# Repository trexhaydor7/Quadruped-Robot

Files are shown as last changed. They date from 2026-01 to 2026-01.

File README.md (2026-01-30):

# Quadruped-Robot
A servo-driven robotic dog controlled by a Raspberry Pi for smooth movement and intelligent autonomous behavior. Along with an intent to implement robust algorithims and mechnanical design, this project is aimed to be open-sourced, well-documented, and meant to spark new ideas in others.

<div align="center">
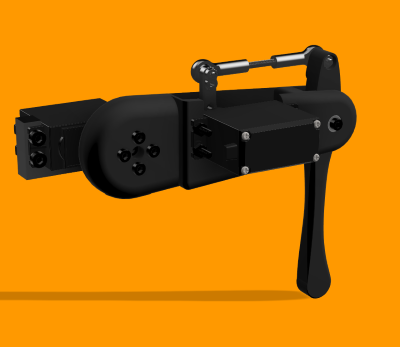
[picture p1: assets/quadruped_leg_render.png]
Quadruped leg design
  
</div>

# Technical Details

This project includes two major software components, a custom CLI interface, named QGC (Quadruped Guidance Computer), and a trained AI model using the Jetson Nano Orion. At the time of writing, neither of these are fully implemented, but I have plans to implement them in the future due to my interest in low-level programming, AI models, and embedded systems engineering. Furthermore, all CAD for the robot was designed by me in Fusion 360 and was printed using on the Bambu Lab H2S using either generic PLA or PETG HF (for particularly critical parts where strength is needed). Other than 3D-printed parts, all parts were ordered from a varity of suppliers, however many Amazon. The electronics of the quadruped robot are composed of the Jetson Orion Nano for high-speed computation and high-level instructions, and the low-level custom PCB that serves as a PWM-driver for all 12 Hi-Torque MG996R servo motors.

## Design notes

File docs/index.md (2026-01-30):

<!--
  ===================    !!READ THIS NOTICE!!   ====================
  DO NOT edit this file manually. Your changes WILL BE OVERWRITTEN!
  This journal is auto generated and updated by Hack Club Blueprint.
  To edit this file, please edit your journal entries on Blueprint.
  ==================================================================
-->

## 10/26/2025 - Prototyped Parts  

I prototyped the servo mount and upper linkage (_femur_) for the **MG996R Hi Torque Servo Motors** that I will be using, utilizing **M3 screws and bolts** to make a more robust build. It took a while to design the servo mount because I spent a lot of time reiterating on the mounting choice (initially I was going to use heated inserts), but bolts will be the most reliable for now. After this I hope to design the lower linkage (_tibia_) of the robot and also the hip mechanism, which could use a differential or some variation.

**Servo Mount for MG996R** 


**Upper Linkage (_Femur_)** 


## 10/31/2025 - Improved Femur Part  

Today, I reiterated on the femur design, **majorly** improving both the **structural aspects**, **functionality** (added room for the second room for controlling the tibia), and the technical side of my **CAD software**, Fusion 360, by assigning more variables for redundant values, using appropriate joints, etc. I think I did a good job of working out the screw tolerances to mount the servo motor to the femur shell. However I think I can work on the strength of the part, as there seems to be some excess support where not need and lack of support for other, more critical areas (mounting holes, pivot points, etc.). Next I plan to work on finally finishing a prototype for the entire leg and get started on a list of electronics for my custom PCB. Stay tuned!

Improved Femur Part (**Side View**)



Improved Femur part (**Rendered**)



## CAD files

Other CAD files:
cad/fusion360/servo_motor_mount.f3z
cad/fusion360/tibia.f3d

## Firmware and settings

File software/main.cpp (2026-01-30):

#include <Servo.h>
#include <Arduino.h>
#include <optional>

#define BOLD "\\033[1m"
#define OFF "\\033[0m"

unsigned long t0;
bool motorsCalibrated = false;
int baudRate = 9600;

int tibiaPin = 5;
int femurPin = 3;

//in mm
float l1 = 100;
float l2 = 90.981;

// Tibia servo range is limit from 47 to 113 degrees
const int TIBIA_MIN = 47;
const int TIBIA_MAX = 113;

const int FEMUR_MIN = 0;
const int FEMUR_MAX = 180;

const int FEMUR_ZERO = 80;
const int TIBIA_ZERO = 95;

Servo femur;
Servo tibia; 

//List of all possible errors
enum ERR {
  ERR_NONE,
  ERR_IK_UNREACHABLE,
  ERR_IK_NAN,
  ERR_IK_FK_MISMATCH,
  ERR_SERVO_LIMIT
};

//List of all possible system modes
enum Mode {
  INIT,
  CALIBRATION,
  RUNNING,
  IDLE
};

//Struct to store an input for calculating inverse kinematics
struct Coordinates {
  double x;
  double y;
  std::optional<int> place; //for index if testing many points for gaits
};

//Struct for result of inverse kinematics calculations
struct Angles {
  double theta1;
  double theta2;
};

//Current error state and mode of the robot 
ERR currentERR;
Mode currentMode; 

void setup() {
  // put your setup code here, to run once
  t0 = millis();
  Serial.begin(baudRate);
  
  while((millis() - t0) < 2000)
  {
    ;
  }

  setERR(ERR_NONE);
  setMode(INIT);

  femur.attach(femurPin);
  tibia.attach(tibiaPin);

  if(!motorsCalibrated)
  {
    setMode(CALIBRATION);
    calibrate();
    motorsCalibrated = true;
  }
  
  setMode(IDLE);
}

void loop() {

  delay(1000);
  if(!motorsCalibrated)
  {
    setMode(CALIBRATION);
    calibrate();
    motorsCalibrated = true;
  }

  Coordinates input{0,-50.00};
  Angles angles = calculateInverseKinematics(input);

  if(currentERR != ERR_NONE) {
    setMode(IDLE);
    return;
  }

  double tibiaDEG = TIBIA_ZERO + angles.theta2 * 180/PI;
  double femurDEG = FEMUR_ZERO + angles.theta1 * 180/PI;

  if(tibiaDEG < TIBIA_MIN || tibiaDEG > TIBIA_MAX)
  {
    setERR(ERR_SERVO_LIMIT);
    return;
  }

  if(femurDEG < FEMUR_MIN || femurDEG > FEMUR_MAX)
  {
    setERR(ERR_SERVO_LIMIT);
    return;
  }

  setERR(ERR_NONE);

  //Generally good practice to isolate calculation from used values
  Angles servoAngles = angles;

  servoAngles.theta1 = constrain( femurDEG, FEMUR_MIN, FEMUR_MAX);
  servoAngles.theta2 = constrain( tibiaDEG, TIBIA_MIN, TIBIA_MAX);

   Coordinates checked = calculateForwardKinematics(angles);
   if(!checkIK(input, checked)) {
    setMode(IDLE);
    return;
   }
   setERR(ERR_NONE);

    Serial.print("Femur Angle:  ");
    Serial.println(servoAngles.theta1);
    Serial.print("Tibia Angle: ");
    Serial.println(servoAngles.theta2);

  setMode(RUNNING);
  femur.write(servoAngles.theta1);
  tibia.write(servoAngles.theta2);
  setMode(IDLE);
  delay(1000);
}

//Helper method to calibrate all servo motors
void calibrate() {
  femur.write(FEMUR_ZERO);
  tibia.write(TIBIA_ZERO);
}

//Helper method to provide information on errors
void printERR(ERR currentERR) {

  Serial.print("[ERROR] ");

  switch(currentERR) {
    case ERR_NONE:
      Serial.println("Ok");
      break;
    case ERR_IK_UNREACHABLE:
      Serial.println("Unreachable coordinate");
      break;
    case ERR_IK_NAN:
      Serial.println("Unreachable coordinate : IK Math caused NaN");
      break;
    case ERR_SERVO_LIMIT:
      Serial.println("Angle desired is out of bounds of servo motor");
      break;
    case ERR_IK_FK_MISMATCH:
      Serial.println("Discrepancy in calculated angles and desired coordinates");
      break;
    default:
      Serial.println("Unknown Error");
      break;
  } 
}

void printMode(Mode currentMode) {

  Serial.print("[SYS] ");

  switch(currentMode) {
    case INIT:
      Serial.println("Initializing quadruped robot");
      break;
    case CALIBRATION:
      Serial.println("Calibrating servo motors");
      break;
    case RUNNING:
      Serial.println("System is running");
      break;
    case IDLE:
      Serial.println("System is idle");
      break;
    default:
      Serial.println("Unknown System mode");
      break;
  } 
}

//Helper method to indicate new system mode of robotic system
void setMode(Mode newMode) {
  if(currentMode == newMode) return;
  currentMode = newMode;
  printMode(currentMode);
}

//Helper method to indicate new erro of robotic system
void setERR(ERR newERR) {
  if(currentERR == newERR) return;
  currentERR = newERR;
  printERR(currentERR);
}


//Function to calculate two angles for desired x and y coordiante
Angles calculateInverseKinematics(Coordinates point) {

  Angles result;
  //If the desired coordinates would throw an mathematical error, default to angle 0 for both angles
  double dist = sqrt(point.x*point.x + point.y*point.y);
    if(dist < 1e-6) {
        setERR(ERR_IK_NAN);
        result.theta1 = 0;
        result.theta2 = 0;
        return result;
    }

  //Check if desired coordinates are not reachable for the given femur and tibia length
  if (dist > l1 + l2 || dist < fabs(l1 - l2)) {
      setERR(ERR_IK_UNREACHABLE);
      result.theta1 = 0;
      result.theta2 = 0;
      return result;
  }

  //Calulate theta 2
  double c2 = (point.x*point.x + point.y*point.y - l1*l1 - l2*l2)/(2.0 * l1 * l2);
  c2 = constrain(c2, -1.0, 1.0);
  result.theta2 = acos(c2);
  
  //Calculate theta 1
  double k1 = l1 + l2 * cos(result.theta2);
  double k2 = l2 * sin(result.theta2);

  double c1 = atan2( (point.y * k1 - point.x * k2), (point.x * k1 + point.y * k2));

  result.theta1 = c1;

  return result;
}

//Function to verify the calculations of inverse kinematics
Coordinates calculateForwardKinematics(Angles angles)
{
    Coordinates result; 

    result.x = l1 * cos(angles.theta1) + l2 * cos(angles.theta1 + angles.theta2);
    result.y = l1 * sin(angles.theta1) + l2 * sin(angles.theta1 + angles.theta2);

    return result;
}


//Helper method to compare desired vs calculated coordinates
bool checkIK(Coordinates input, Coordinates checked)
{
  //Include some tolerance for desired vs calculated coordinates
  const double EPS = 2.0;
  
  if(fabs(input.x - checked.x) < EPS && fabs(input.y - checked.y) < EPS)
  {
    return true;
  } else
  {
    setERR(ERR_IK_FK_MISMATCH);
    return false;
  }
}

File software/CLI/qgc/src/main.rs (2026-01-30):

/*  I want QGC (Quadruped Guidance Computer)to take configurations from Raspberry files and other custom config files for my quadruped robot.
Then it will report them in a structure format for reading critical metrics/debugging. I also want it to have a mode to actually control
the robot, including using simple commands for single motors all the way to moving the leg to a specific point using inverse kinematics. 
Above all, it must be a terminal tool, have easy debugging, extensive documentation, optimized for speed and memory usage, and intuitive to use.
*/

fn main() {
    println!("QGC Initialized");
    
}

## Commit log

2026-01-29 Update JOURNAL.md with design progress and plans
    Documented progress on the femur and tibia designs, including modifications and future plans for coding inverse kinematics.
2026-01-29 Clean up JOURNAL.md by removing old design notes
    Removed detailed progress notes and images related to design modifications, motor adjustments, and future plans for coding and prototyping.
2026-01-30 Refactor inverse kinematics and servo calibration logic
    Included errors and mode reporting for logging and debugging.
    [main.cpp]
2026-01-30 Include image in README for quadruped robot
    Add image of quadruped leg design to README
2026-01-30 Create cad dir
2026-01-30 Added Fusion360 files of leg
    [servo_motor_mount.f3z, tibia.f3d]
2026-01-30 Add main.cpp for robotic control and kinematics
